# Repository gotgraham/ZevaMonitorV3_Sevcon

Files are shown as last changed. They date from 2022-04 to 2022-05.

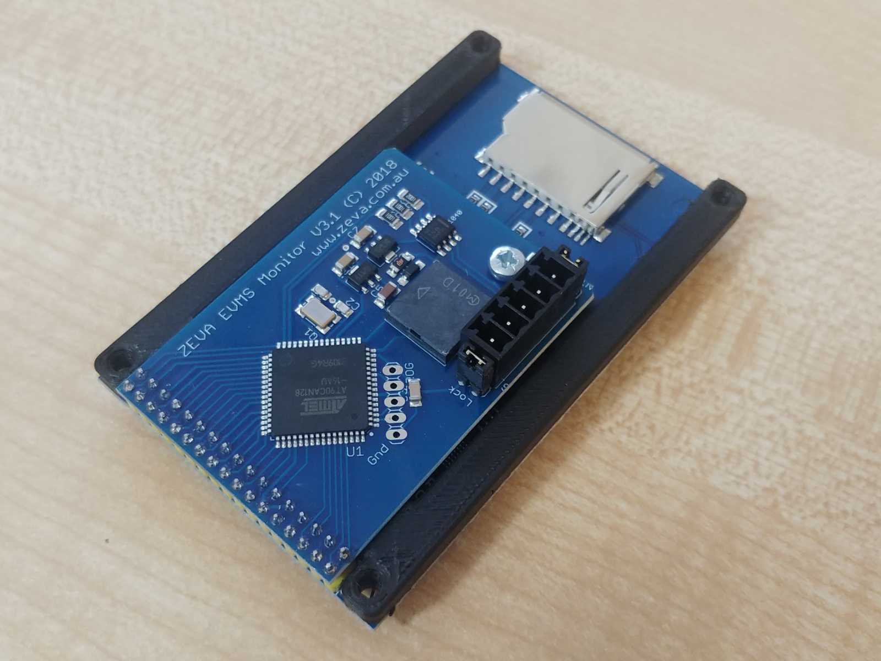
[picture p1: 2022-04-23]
Example Pictures/Assembled internals.jpg

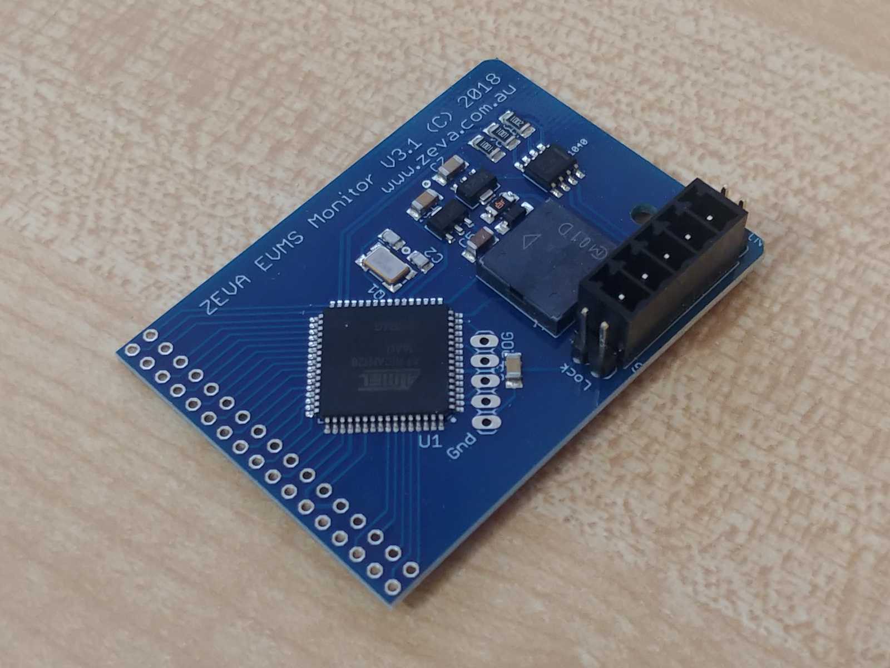
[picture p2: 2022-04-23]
Example Pictures/Control board.jpg

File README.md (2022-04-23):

# ZevaMonitorV3_SevconGen4

This project is based on the now open source Zeva EVMS Monitor V3 from Ian Hooper. It has an MIT license as does Ian's original source.

It retains all the existing EVMS Monitor V3 features, and adds an additional screen for monitoring live parameters from a Sevcon Gen 4 controller.

- Motor Temp
- Motor RPM
- Controller Temp
- Velocity
- Phase Amps
- ...

To build:

Install avr-gcc

From the Firmware directory, run 'make all'. The makefile supports 'make all', 'make clean', and 'make flash'

Status:

 WIP

ZEVA EVMS Monitor V3
  Ian Hooper, August 2021

This archive contains all the files needed to reproduce the ZEVA EVMS Monitor V3, a touchscreen interface device for the EVMS3. Files are provided under the open source MIT license, found at the end of this file. The short version is that you may use these files for any purpose, free of charge, but they don’t come with any warranty or support.

PCB and schematic (.sch) files can be opened in Autodesk Eagle. If you don’t need to modify the design, the Gerber files in the PCB Assembly folder can be sent as-is to a PCB manufacturer to get boards made. Files for PCB assembly are also included, such as a Bill of Materials, centroid files (for pick-and-place machines), and example photos for reference. Parts in the Eagle file may not match the BoM in some cases. If in doubt, trust the BoM.

The LCD panels can be purchased off Alibaba or AliExpress - just search for “3.2 TFT LCD”, and look for pictures that match the example supplied with this download. Some example vendors are TZT, YTF, EQV, HESAI, Roarkit.

The firmware is written is C and can be compiled using AVR-GCC, normally using an IDE such as AVR / Microchip Studio. No claims are made about the quality or readability of the code. (This Monitor code in particular may be a bit of an impenetrable monolith if you’re not familiar with it - my apologies.) A precompiled HEX file is also supplied, which can be loaded onto boards as-is if standard firmware is suitable.

You will need an AVRISP type programming device for transferring firmware to the board, such as AVRISP MK2, STK500 or USBASP. The programming port on the PCB is a row of 5 holes near the microcontroller, with pin order GND, MOSI, MISO, SCK, RESET (with GND end marked). It is different to the usual 3x2 or 5x2 pin port used by AVRISP programmers, so you will need to make an adapter using 5 wires and some 0.1” pin header. Normally the 5x1 pin header can be pressed against the PCB holes during programming (avoids the need to add any connector to the board). The board will need to be powered during programming via 12V supplied to the CAN bus port.

AVR microcontrollers use “fuses” for setting things like the clock speed and brownout detection. The required fuse settings are listed near the top of the C code file.

There is a PCB support bracket that should be 3D printed, which gets fitted between the LCD module and the control board, and fastened to the control board using an M3x6 machine screw. Then the control board can be soldered to the 34x interface pins on the LCD module to complete the internal assembly. There are two housing options supplied, one panel mount which gets attached to the assembly using 4x M3x10 machine screws, or an enclosed housing with foot which gets screwed together using 4x M3x16 countersunk machine screws, and the foot can be attached using an M3x20 machine screw plus M3 nyloc nut. The mating connector for the CAN bus port is Molex 39500-0005. Remember to also fit jumpers to the two 2-pin headers either side of the CAN port, for the CAN termination resistor and to disable settings lock.

Once assembled and programmed, the EVMS Monitor should be ready to use. Please review the EVMS3 user manual for further information about installation and operation.

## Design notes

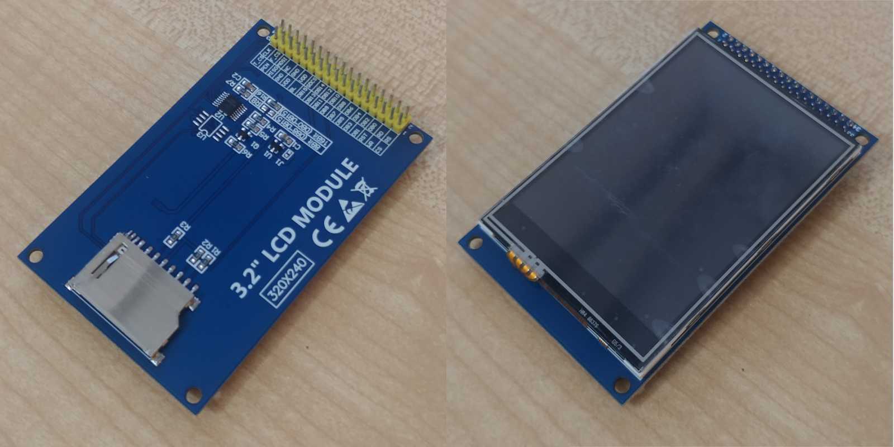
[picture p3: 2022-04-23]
Example Pictures/LCD Module.jpg

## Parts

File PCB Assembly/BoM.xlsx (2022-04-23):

Qty | Designator | Description or part number | Package | Total pads | Total pins
1 | Q1 | ABM3B-16.000MHZ-10-1-U-T | CTS406 | 4
1 | D1 | B5819W-TP | SOD123 | 2
2 | CANTERM, CONFIG_LOCK | Standard 0.1" pitch pin headers, 2x1 | 1X02 |  | 4
0 | PROG | Leave empty | 1X05
0 | QDTECH_LCD | Leave empty | 2X17
1 | C3 | 0.1uF 50V 1206 X7R capacitor | C1206 | 2
1 | R4 | 120ohm 1% 1206 resistor | R1206 | 2
2 | C1, C2 | 10pF 0805 C0G capacitor | C0805 | 4
2 | R1, R2 | 1Kohm 1% 1206 resistor | R1206 | 4
2 | C7, C9 | 1uF 16V 1206 X7R capacitor | C1206 | 4
1 | U$5 | 0ZCJ0020FF2E | 1206 | 2
1 | R3 | 2Kohm 1% 1206 resistor | R1206 | 2
1 | IC1 | L78L33ABUTR | SOT89R | 3
1 | C5 | 47uF 16V 1206 ceramic capacitor | C1206 | 2
1 | IC2 | L78L05ABUTR | SOT89R | 3
1 | U1 | AT90CAN64-16AU | TQFP64-0.8MM | 64
1 | SN65HVD1040 | SN65HVD1040QDRQ1 | SOIC8 | 8
1 | U$1 | 39501-1005 | MOLEX-39501-1005 |  | 5
1 | U$6 | PKLCS1212E4001-R1 | PKLCS1212E_PIEZO | 2
21 |  | (TOTALS LINE) |  | 108 | 9

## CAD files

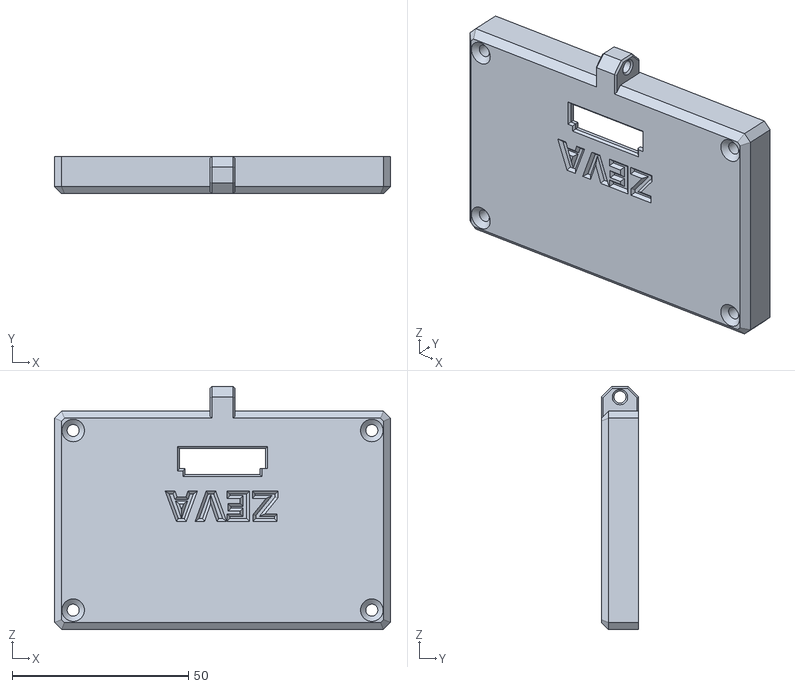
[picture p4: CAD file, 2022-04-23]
Housing/Enclosed Housing - Rear.STL
95.4 x 10.6 x 69.0

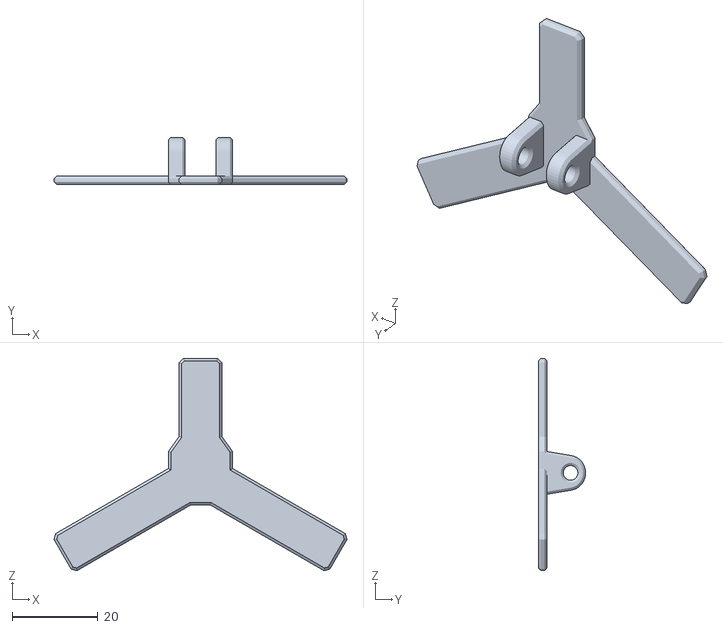
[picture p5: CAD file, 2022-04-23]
Housing/Enclosed Housing - Mounting Foot.STL
68.5 x 11.0 x 49.6

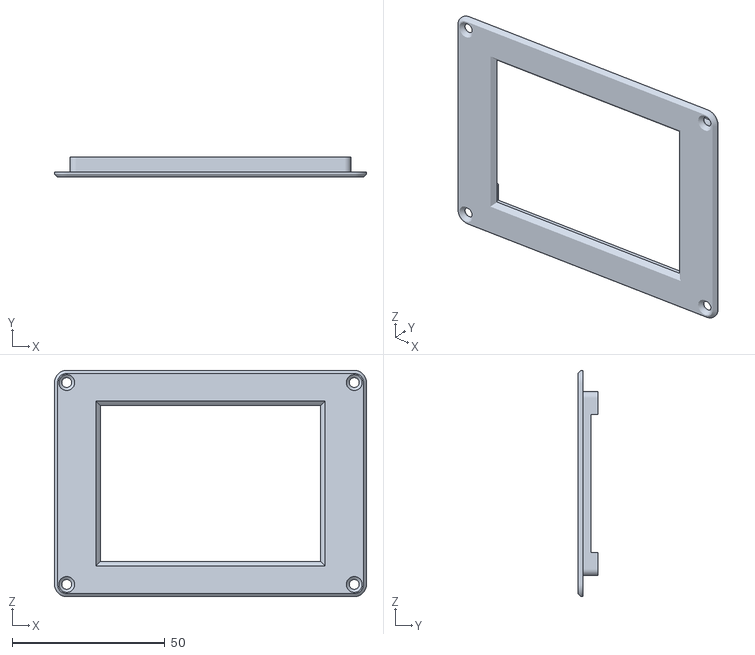
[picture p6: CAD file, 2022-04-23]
Housing/Panel Mount Fascia.STL
102.0 x 6.60 x 74.0

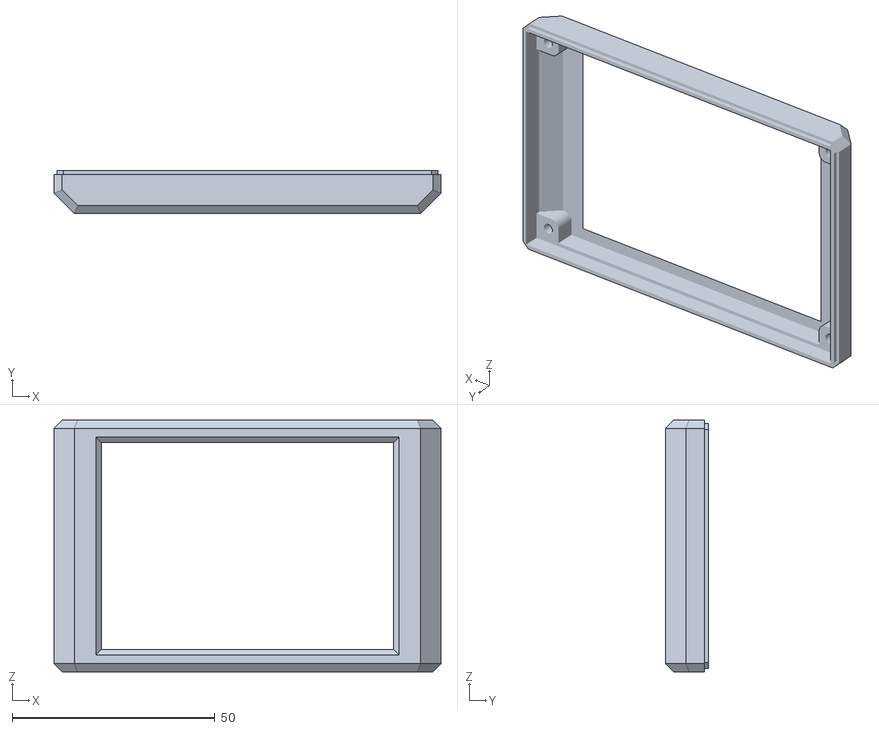
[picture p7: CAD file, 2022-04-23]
Housing/Enclosed Housing - Front.STL
95.4 x 10.6 x 62.0

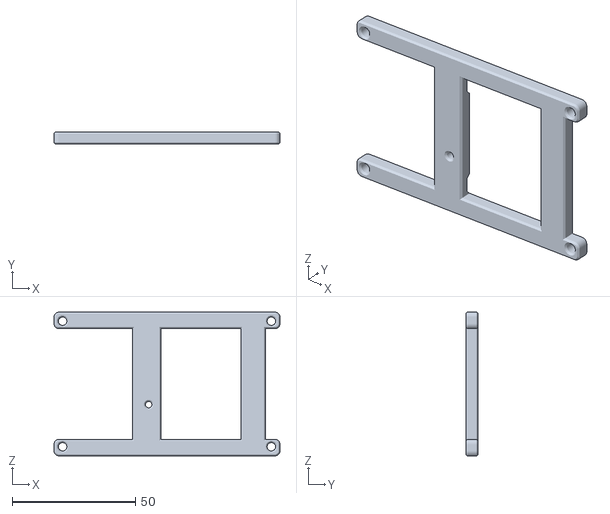
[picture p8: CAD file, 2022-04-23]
Housing/PCB Support.STL
91.8 x 5.00 x 58.4

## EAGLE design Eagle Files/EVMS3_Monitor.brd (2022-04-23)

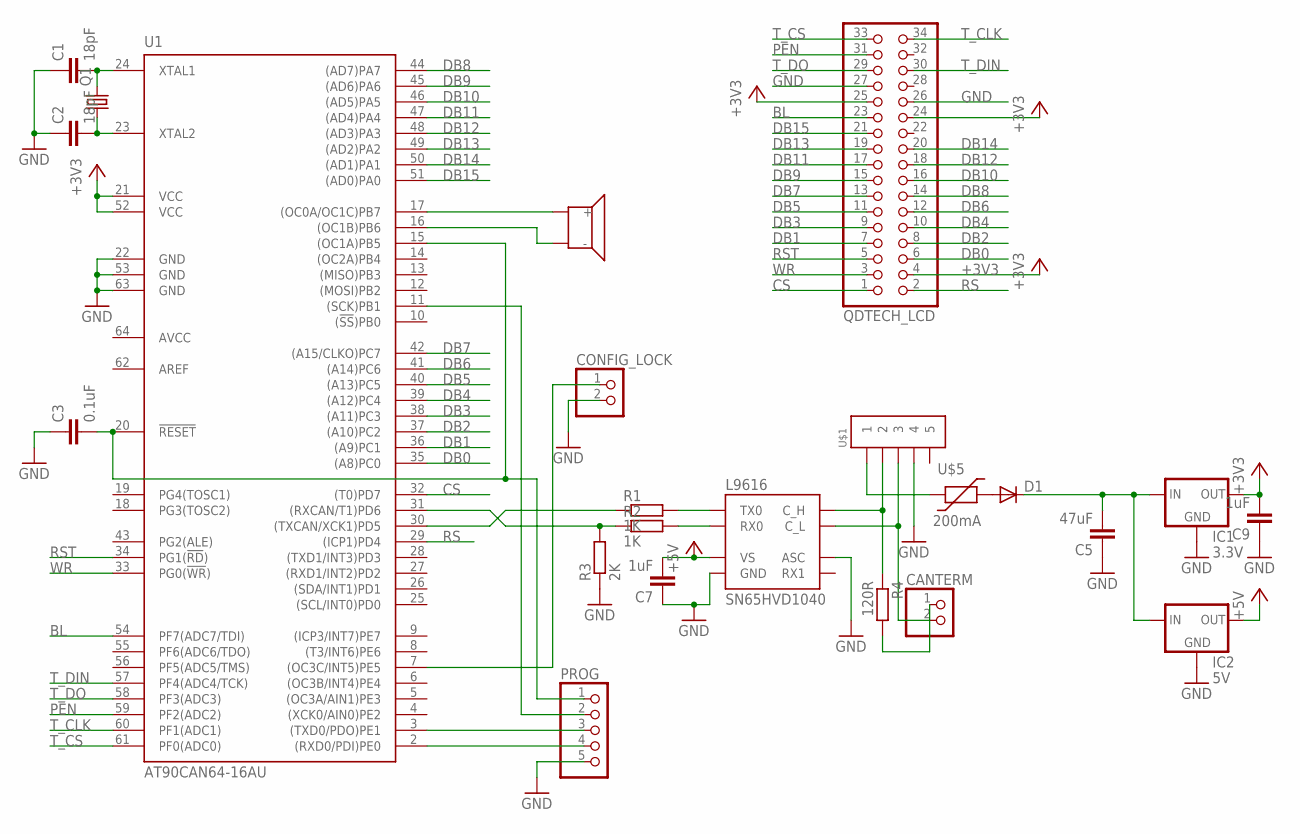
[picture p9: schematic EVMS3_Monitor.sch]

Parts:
C1, C2: 18pF; C0805
C3: 0.1uF; C1206
C5: 47uF; C1206
C7, C9: 1uF; C1206
CANTERM: PINHD-1X2; 1X02
CONFIG_LOCK: PINHD-1X2; 1X02
D1: DIODE-SOD123; SOD123
IC1: 3.3V; SOT89R
IC2: 5V; SOT89R
PROG: PINHD-1X5; 1X05
Q1: CRYSTALCTS406; CTS406
QDTECH_LCD: PINHD-2X17; 2X17
R1, R2: 1K; R1206
R3: 2K; R1206
R4: 120R; R1206
SN65HVD1040: L9616; SOIC8
U1: AT90CAN64-16AU; TQFP64-0.8MM
U$1: MOLEX-39502-1005VERT; MOLEX-39501-1005
U$5: 200mA; 1206
U$6: MURATA_PIEZO; PKLCS1212E_PIEZO

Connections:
+3V3: C9.2, IC1.2 (OUT), QDTECH_LCD.4, QDTECH_LCD.24, QDTECH_LCD.25, U1.21 (VCC), U1.52 (VCC)
+5V: C7.2, IC2.2 (OUT), SN65HVD1040.P$3 (VS)
AVCC: U1.64 (AVCC)
BL: QDTECH_LCD.23, U1.54 (PF7(ADC7/TDI))
BUZZER: U1.17 ((OC0A/OC1C)PB7), U$6.1 (+)
CS: QDTECH_LCD.1, U1.32 ((T0)PD7)
DB0: QDTECH_LCD.6, U1.35 ((A8)PC0)
DB1: QDTECH_LCD.7, U1.36 ((A9)PC1)
DB2: QDTECH_LCD.8, U1.37 ((A10)PC2)
DB3: QDTECH_LCD.9, U1.38 ((A11)PC3)
DB4: QDTECH_LCD.10, U1.39 ((A12)PC4)
DB5: QDTECH_LCD.11, U1.40 ((A13)PC5)
DB6: QDTECH_LCD.12, U1.41 ((A14)PC6)
DB7: QDTECH_LCD.13, U1.42 ((A15/CLKO)PC7)
DB8: QDTECH_LCD.14, U1.44 ((AD7)PA7)
DB9: QDTECH_LCD.15, U1.45 ((AD6)PA6)
DB10: QDTECH_LCD.16, U1.46 ((AD5)PA5)
DB11: QDTECH_LCD.17, U1.47 ((AD4)PA4)
DB12: QDTECH_LCD.18, U1.48 ((AD3)PA3)
DB13: QDTECH_LCD.19, U1.49 ((AD2)PA2)
DB14: QDTECH_LCD.20, U1.50 ((AD1)PA1)
DB15: QDTECH_LCD.21, U1.51 ((AD0)PA0)
GND: C1.1, C2.1, C3.1, C5.1, C7.1, C9.1, CONFIG_LOCK.2, IC1.4 (GND), IC2.4 (GND), PROG.5, QDTECH_LCD.26, QDTECH_LCD.27, R3.1, SN65HVD1040.P$2 (GND), SN65HVD1040.P$8 (ASC), U1.22 (GND), U1.53 (GND), U1.63 (GND), U$1.4
unnamed: C3.2, PROG.1, U1.15 ((OC1A)PB5), U1.20 (!RESET)
unnamed: C1.2, Q1.3 (2), U1.24 (XTAL1)
unnamed: C2.2, Q1.1, U1.23 (XTAL2)
unnamed: PROG.4, U1.2 ((RXD0/PDI)PE0)
unnamed: PROG.3, U1.3 ((TXD0/PDO)PE1)
unnamed: PROG.2, U1.11 ((SCK)PB1)
unnamed: R1.1, U1.30 ((TXCAN/XCK1)PD5)
unnamed: C5.2, D1.C, IC1.1 (IN), IC2.1 (IN)
unnamed: R2.1, R3.2, U1.31 ((RXCAN/T1)PD6)
unnamed: R1.2, SN65HVD1040.P$1 (TX0)
unnamed: R2.2, SN65HVD1040.P$4 (RX0)
unnamed: CONFIG_LOCK.1, U1.7 ((OC3C/INT5)PE5)
unnamed: R4.1, SN65HVD1040.P$7 (C_H), U$1.2
unnamed: CANTERM.2, SN65HVD1040.P$6 (C_L), U$1.3
unnamed: CANTERM.1, R4.2
unnamed: U1.16 ((OC1B)PB6), U$6.2 (-)
unnamed: D1.A, U$5.P$2
unnamed: U$1.1, U$5.P$1
PEN: QDTECH_LCD.31, U1.59 (PF2(ADC2))
RS: QDTECH_LCD.2, U1.29 ((ICP1)PD4)
RST: QDTECH_LCD.5, U1.34 (PG1(!RD!))
T_CLK: QDTECH_LCD.34, U1.60 (PF1(ADC1))
T_CS: QDTECH_LCD.33, U1.61 (PF0(ADC0))
T_DIN: QDTECH_LCD.30, U1.57 (PF4(ADC4/TCK))
T_DO: QDTECH_LCD.29, U1.58 (PF3(ADC3))
WR: QDTECH_LCD.3, U1.33 (PG0(!WR!))

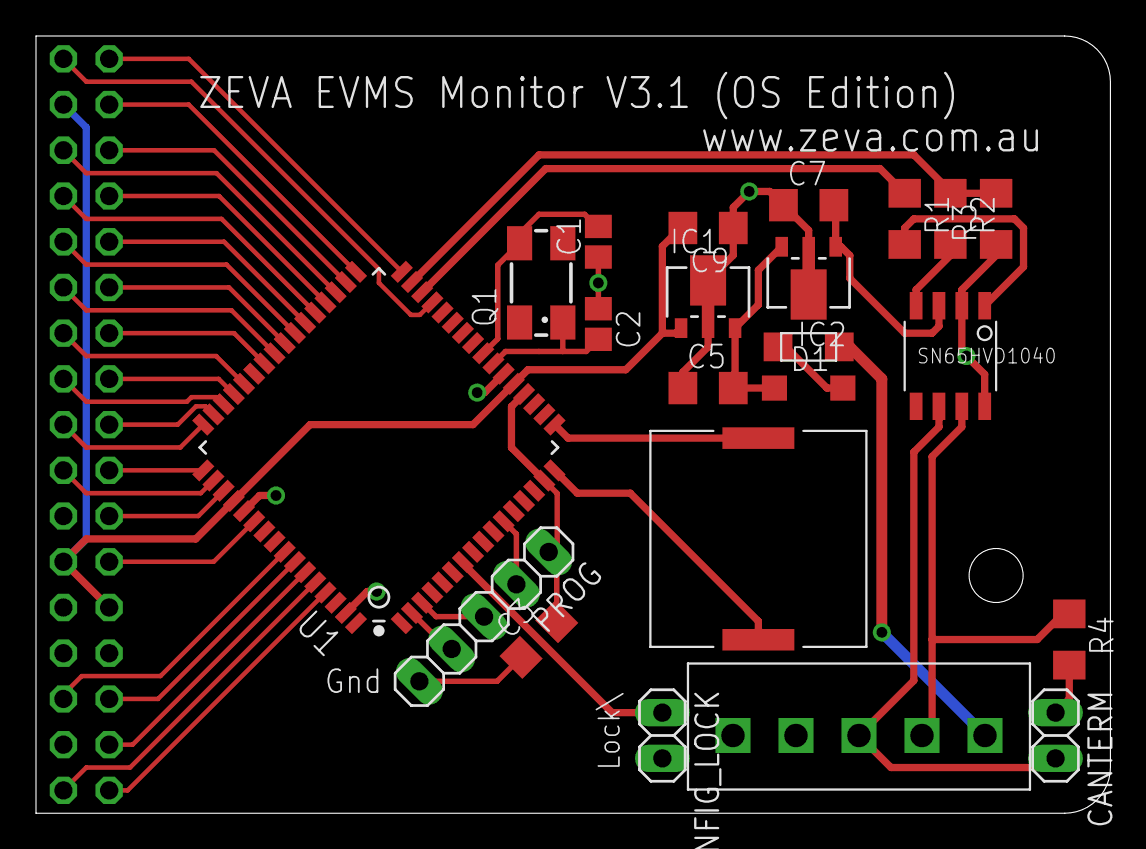
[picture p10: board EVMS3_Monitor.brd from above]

Board: 2 copper layers, 59.7 x 43.2 mm, 23 parts (1 on the bottom side), 48 nets.

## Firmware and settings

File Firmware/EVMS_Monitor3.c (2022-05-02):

// EVMS Monitor V3
// Open Source version, released under MIT License (see Readme file)
// Last modified by Ian Hooper (ZEVA), August 2021

// Code for AT90CAN64 (also suitable for AT90CAN128)
// Fuses: 16Mhz external crystal, CKDIV8 off, JTAGEN off

// Note: Various #defined build options found in Common.h file

#define __DELAY_BACKWARD_COMPATIBLE__

#define DISPLAY_TYPE	ILI9341		// SSD1289 or ILI9325 or ILI9341
#define SHOW_TOUCH_LOCATION	0 // Used for debugging touchscreen - writes touched coords in top left
#define FAKE_EVMS	0 // Use to test things if no EVMS is present
#define MONITOR // Modifies some stuff in the Common.h header

#define MAX_BMS_MODULES	16

#include <inttypes.h>
#include <stdlib.h>
#include <string.h>
#include <avr/io.h>
#include <avr/eeprom.h>
#include <avr/interrupt.h>
#include <avr/pgmspace.h>
#include <util/delay.h>
#include <stdbool.h>

#include "Common.h"
#include "Touchscreen.h"
#include "config.h"
#include "can_lib.h"

// Colour theme - only partially implemented
#define BGND_COLOUR		BLACK
#define LABEL_COLOUR	BLUE // RED
#define TEXT_COLOUR		WHITE // RED
#define CHARGING_COLOUR	BLUE // RED
#define RUNNING_COLOUR	GREEN // RED
#define SOC_COLOUR		0		// or 0 to use green-to-red dynamic colouring

#define BUZZER	(1<<PB7)
#define BUZZER2	(1<<PB6)

#define CONFIG_LOCK	(PIND & (1<<PD0)) // Config lock normally pulled down (off) by jumper, i.e remove jumper to lock
#define CONFIG_LOCK2 (PINE & (1<<PE5)) // PCB version 3.1 reassigned this - but code should support both

#ifdef NEW_LCD
#define BACKLIGHT		(1<<PF7)
#define BACKLIGHT_PORT	PORTF
#define BACKLIGHT_DDR	DDRF
#else
#define BACKLIGHT		(1<<PD7)
#define BACKLIGHT_PORT	PORTD
#define BACKLIGHT_DDR	DDRD
#endif

// Initialising all the buttons
typedef struct
{
	int x, y, width;
	U16 colour;
	char* text;
	bool isTouched;
} Button;

Button enterSetupButton = { 160, 30, 220, BLUE, "Enter Setup", false };
Button resetSocButton = { 160, 70, 220, GREEN, "Reset SoC", false };
Button zeroCurrentButton = { 160, 110, 220, GREEN, "Zero Current", false };
Button displayOffButton = { 160, 150, 220, GREEN, "Display Off", false };
Button exitOptionsButton = { 160, 190, 220, ORANGE, "Exit Options", false };

Button nextBmsModuleButton = { 260, 200, 100, GREEN, "Next", false };
Button prevBmsModuleButton = { 60, 200, 100, GREEN, "Prev", false };

Button changeSetupPageButtonLeft = { 40, 25, 80, BLUE, "<", false };
Button changeSetupPageButtonRight = { 280, 25, 80, BLUE, ">", false };
Button changeParameterButtonLeft = { 40, 90, 80, BLUE, "<", false };
Button changeParameterButtonRight = { 280, 90, 80, BLUE, ">", false };
Button changeValueButtonLeft = { 40, 155, 80, BLUE, "<", false };
Button changeValueButtonRight = { 280, 155, 80, BLUE, ">", false };
Button exitSetupButton = { 160, 207, 160, ORANGE, "Exit Setup", false };

Button* touchedButton = 0;

short cellVoltages[MAX_BMS_MODULES][12]; // Buffer for holding last cell voltages
U8 bmsTemps[MAX_BMS_MODULES][2];

long current = 0;
int currentSensorTimeout = 0;
char haveReceivedCurrentData = false;

unsigned char mcStatusBytes[8];
unsigned char sevStatus0Bytes[8];
unsigned char sevStatus1Bytes[8];

short mcCanTimeout = 0;

char haveReceivedEVMSData = 0;
char haveReceivedMCData = 1;

short chargerCommsTimeout[3] = { 0, 0, 0 };

short ticksSincePowerOn = 0;

// Display pages
enum { EVMS_CORE, MOTOR_CONTROLLER, TC_CHARGER, BMS_SUMMARY, BMS12_DETAILS, NUM_KNOWN_DEVICES };

// Function declarations
void PrepareCanRX(unsigned char mob);
void ProcessCanRX(unsigned char mob);
void HandleTouchDown();
void HandleTouchUp();
void DoSetupButtons(char isKeyRepeat);
void TransmitSettings();
void TransmitGaugeState();
static inline void Beep(short ticks);
static inline void UpdateBuzzer();
void AddDecimalPoint(char* buffer);
void AddDecimalPoint2(char* buffer);
void SetupPorts();
char LoadSettingsFromEEPROM();
void SaveSettingsToEEPROM();
void CanTX(long packetID, unsigned char* data, unsigned char length, unsigned char delayAfterSending);
void RenderStartupScreen();
void RenderMainView();
void RenderMainViewNoCurrentSensor();
void RenderLiteIdleScreen();
void RenderMCStatus();
void RenderChargerStatus();
void RenderThreeChargerStatus();
void RenderBMSSummary();
void RenderBMSDetails();
void RenderWarningOverlay();
void RenderOptionsButtons();
static inline void RenderBorderBox(int lx, int ly, int rx, int ry, U16 Fcolor, U16 Bcolor);
void RenderButton(Button* button, bool needsRedraw);
void RenderSettings();

// Global variables

#define NUM_RX_MOBS	4 // Four RX MOBs for CAN messages
st_cmd_t rxMsg[NUM_RX_MOBS];
U8 rxData[NUM_RX_MOBS][8];

U8 txData[8]; // CAN transmit buffer

char buffer[30]; // Used for sprintf functions

short ticks = 0; // For main loop timing

volatile uint8_t evmsStatusBytes[8];

signed char displayedPage = MOTOR_CONTROLLER;

volatile bool displayNeedsFullRedraw = true;
bool showOptionsButtons;
bool showStartupScreen = true;

short coreStatus;
char isBMS16 = false; // Monitor can tell the difference based on CAN data, changes displays etc a little
char isActuallyBMS12i = false; // has a bit of a dirty hack to differentiate BMS16 and BMS12i

unsigned char error = NO_ERROR;
char evmsCommsTimer = 0;
char resetSoCsent = false;

short beepTimer = 0;
short errorBeeperTimeout = 0;
short touchTimer;
int touchX, touchY;
int touchBufferX[10], touchBufferY[10];

enum { NOTHING_TO_SEND, SEND_RESET_SOC, SEND_ZERO_CURRENT, SEND_ENTER_SETUP, SEND_GAUGE_STATE, SEND_SETTINGS, SEND_ACK_ERROR };
short canToGo;

short displayBrightness = 255;
short targetDisplayBrightness; // (Used for smoothly fading brightness)
bool  displayDimmed;
bool  headlightsOn = 0;

char canTXing = false;

bool setupMode = false;

int numCells = 0;

enum { GENERAL_SETTINGS, MC_SETTINGS, PACK_SETUP };
char settingsPage = GENERAL_SETTINGS;
short currentParameter = 0;
short currentBmsModule = 0;

short mcCurrentParameter = 0;

typedef struct {
	// These come from the charger
	short instVoltage;
	short instCurrent;
	unsigned char statusBits;
	unsigned char temp;
	// These go to the charger
	short targetVoltage;
	short targetCurrent;
	char controlBit;
} ChargerData;
ChargerData charger[3] = {{ 0, 0, 0, 0, 0, 0, 0 }, { 0, 0, 0, 0, 0, 0, 0 }, { 0, 0, 0, 0, 0, 0, 0 }};
char haveReceivedChargerData = false;
char numChargers = 1; // Gets set to 3 if we receive data from third charger

static inline bool ButtonTouched(Button* button)
{
	return (touchX >= button->x-button->width/2 && touchX <= button->x+button->width/2
		&& touchY >= button->y && touchY <= button->y + 32);
}

static inline void DisplayOn(bool on, bool shouldSaveToEEPROM)
{
	if (true) //on)
	{
		if (displayDimmed || headlightsOn)
			targetDisplayBrightness = 254 - settings[NIGHT_BRIGHTNESS]*settings[NIGHT_BRIGHTNESS] * 5/2;
			// May 2016: Testing quadratic display brightness
			// April 2019: Using 254 so there's a difference between 0% night brightness and actually off (255), though both are black
		else
			targetDisplayBrightness = 0; // Full bright
	}
	else
		targetDisplayBrightness = 255;

	if (shouldSaveToEEPROM)
	{
		eeprom_write_byte((U8*)EEPROM_DISPLAY_BRIGHTNESS, targetDisplayBrightness);
		eeprom_write_byte(0, 0); // Park EEPROM pointer to prevent corruption
	}
}

char toggley;
SIGNAL(TIMER0_OVF_vect) // Called at 7812Hz, i.e every 2048 cycles of 16Mhz clock
{
	ticks++; // Used for main loop timing

#ifdef NEW_LCD
	BACKLIGHT_PORT &= ~BACKLIGHT;

	if (beepTimer > 0)
	{
		if (toggley)
		{
			PORTB |= BUZZER;
			PORTB &= ~BUZZER2;
			toggley = 0;
		}
		else
		{
			PORTB &= ~BUZZER;
			PORTB |= BUZZER2;
			toggley = 1;
		}
	}
	else
		PORTB &= ~(BUZZER + BUZZER2); // Turn both off if not beeping
#else
	BACKLIGHT_PORT |= BACKLIGHT;
#endif

	if (!canTXing && (ticks & 0x07) == 0) // every 8th interrupt, or around 1000hz
	{
		for (int mob=0; mob<NUM_RX_MOBS; mob++)
		{
			U8 temp = can_get_status(&rxMsg[mob]);

			if (temp == CAN_STATUS_COMPLETED) // Then we have received a frame
				ProcessCanRX(mob);

			if (temp == CAN_STATUS_ERROR)
				PrepareCanRX(mob); // And flad a comms error?
		}
	}
}

SIGNAL(TIMER0_COMP_vect)
{
	if (displayBrightness < 254) // 254 is for 0% night brightness, and 255 is for actually off, but both should have no backlight
#ifdef NEW_LCD
		BACKLIGHT_PORT |= BACKLIGHT;
#else
		BACKLIGHT_PORT &= ~BACKLIGHT;
#endif
}

SIGNAL(TIMER1_OVF_vect) // Interrupts at about 30Hz
{
	// Update display brightness
	if (targetDisplayBrightness > displayBrightness)
		displayBrightness += Cap(targetDisplayBrightness-displayBrightness, 0, 15); // Change by 15 maximum
	if (targetDisplayBrightness < displayBrightness)
		displayBrightness -= Cap (displayBrightness-targetDisplayBrightness, 0, 15);

	// Stay dark for half second to receive data from available devices - suppress initial "Waiting for data" page
	if (ticksSincePowerOn < 1) displayBrightness = 255;

	OCR0A = displayBrightness; // Updates backlight PWM, inverted due to PNP transistor

	// Poll touchscreen
	if (Touch_DataAvailable())
	{
		Touch_Read();

		touchTimer++;
		//touchX = Touch_GetX(); // these now in function below - delete here
		//touchY = Touch_GetY();
		HandleTouchDown();
	}
	else
	{
		if (touchTimer > 0) HandleTouchUp();

		touchTimer = 0;
		touchX = -1;
		touchY = -1;
	}

	UpdateBuzzer();
}

void PrepareCanRX(unsigned char mob)
{
	rxMsg[mob].pt_data = rxData[mob];
	for (int n=0; n<8; n++) rxData[mob][n] = 0;

	if (USE_29BIT_IDS) rxMsg[mob].ctrl.ide = true;

	rxMsg[mob].cmd = CMD_RX_DATA;

	while (can_cmd(&rxMsg[mob]) != CAN_CMD_ACCEPTED) { } // Wait for RX command to be completed
}

// This function gets called when a new CAN message is received
void ProcessCanRX(unsigned char mob)
{
	long packetID = rxMsg[mob].id.std;
	if (USE_29BIT_IDS) packetID = rxMsg[mob].id.ext;

	if (packetID >= BMS_BASE_ID && packetID < BMS_BASE_ID+MAX_BMS_MODULES*10+10) // Packet ID within BMS module range
	{
		int moduleID = (packetID - BMS_BASE_ID)/10;
		int packetType = packetID - BMS_BASE_ID - moduleID*10;

		if (moduleID < MAX_BMS_MODULES)
		{
			switch (packetType)
			{
				case BMS_REPLY1:
					for (int n=0; n<4; n++)
						cellVoltages[moduleID][n] = (rxData[mob][n*2]<<8) + rxData[mob][n*2+1];
					break;

				case BMS_REPLY2:
					for (int n=0; n<4; n++)
						cellVoltages[moduleID][n+4] = (rxData[mob][n*2]<<8) + rxData[mob][n*2+1];
					break;

				case BMS_REPLY3:
					for (int n=0; n<4; n++)
						cellVoltages[moduleID][n+8] = (rxData[mob][n*2]<<8) + rxData[mob][n*2+1];
					if (moduleID == 0 && isBMS16) isActuallyBMS12i = true; // If received this third voltages set, sender must be BMS12i
					break;

				case BMS_REPLY4:
					bmsTemps[moduleID][0] = rxData[mob][0];
					bmsTemps[moduleID][1] = rxData[mob][1];
					break;
			}
		}
	}
	else switch (packetID)
	{
		case CORE_BROADCAST_STATUS:
			for (int n=0; n<8; n++) evmsStatusBytes[n] = rxData[mob][n];
			evmsCommsTimer = 0;
			haveReceivedEVMSData = true;
			if (evmsStatusBytes[5] == 255)
			{
				isBMS16 = true;
				displayOffButton.text = "Power off";
				//displayOffButton.colour = BLUE;
			}
			headlightsOn = evmsStatusBytes[6]>>7;
			DisplayOn(targetDisplayBrightness != 255, false);
			break;

		case CAN_CURRENT_SENSOR_ID:
			current = ((long)rxData[mob][0]<<16) + ((long)rxData[mob][1]<<8) + (long)rxData[mob][2] - 8388608L;
			currentSensorTimeout = 4; // 1 second timeout
			if (!haveReceivedCurrentData)
			{
				haveReceivedCurrentData = true;
				displayNeedsFullRedraw = true;
			}
			break;

		case MC_STATUS_PACKET_ID:
			for (int n=0; n<8; n++) mcStatusBytes[n] = rxData[mob][n];
			mcCanTimeout = 4;
			haveReceivedMCData = true;
			/*
			if (showStartupScreen && ticksSincePowerOn >= 2) // MC has lower priority than EVMS, let EVMS go first
			{
				showStartupScreen = false;
				displayNeedsFullRedraw = true;
				displayedPage = MOTOR_CONTROLLER;
			}
			*/
			break;

		case SEV_STATUS_0:
			// <MotorTemp 16t> <Throttle Input Voltage 16> <RPM 32>
			for (int n=0; n<8; n++) sevStatus0Bytes[n] = rxData[mob][n];
			mcCanTimeout = 4;
			haveReceivedMCData = true;
			break;

		case SEV_STATUS_1:
			// <Dig Inputs 8> <Cap Voltage 16> <Batt Current 16> <Heatsink Temp 8> <Batt voltage 16>
			for (int n=0; n<8; n++) sevStatus1Bytes[n] = rxData[mob][n];
			mcCanTimeout = 4;
			haveReceivedMCData = true;
			break;

		case MC_SEND_SETTINGS_ID:
			for (int n=0; n<4; n++) mcSettings[n] = rxData[mob][n]; // First four match 1:1
			mcSettings[MC_RAMP_RATE] = rxData[mob][4]&0b00001111; // Bottom 4 bits hold ramp rate
			mcSettings[MC_SPEED_CONTROL_TYPE] = (rxData[mob][4]&0b00110000)>>4;
			mcSettings[MC_TORQUE_CONTROL_TYPE] = (rxData[mob][4]&0b11000000)>>6;
			for (int n=5; n<8; n++) mcSettings[n+2] = rxData[mob][n];
			break;

		case TC_CHARGER1_RX_ID:
			charger[0].targetVoltage = rxData[mob][0]*256+rxData[mob][1];
			charger[0].targetCurrent = rxData[mob][2]*256+rxData[mob][3];
			charger[0].controlBit = rxData[mob][4];
			break;

		case TC_CHARGER1_TX_ID:
			charger[0].instVoltage = rxData[mob][0]*256+rxData[mob][1];
			charger[0].instCurrent = rxData[mob][2]*256+rxData[mob][3];
			charger[0].statusBits = rxData[mob][4];
			charger[0].temp = rxData[mob][5];
			chargerCommsTimeout[0] = 12; // Three seconds with 4hz loop
			haveReceivedChargerData = true;
			break;

		case TC_CHARGER2_RX_ID:
			charger[1].targetVoltage = rxData[mob][0]*256+rxData[mob][1];
			charger[1].targetCurrent = rxData[mob][2]*256+rxData[mob][3];
			charger[1].controlBit = rxData[mob][4];
			break;

		case TC_CHARGER2_TX_ID:
			charger[1].instVoltage = rxData[mob][0]*256+rxData[mob][1];
			charger[1].instCurrent = rxData[mob][2]*256+rxData[mob][3];
			charger[1].statusBits = rxData[mob][4];
			charger[1].temp = rxData[mob][5];
			chargerCommsTimeout[1] = 12; // Three seconds with 4hz loop
			if (numChargers<2) numChargers = 2;
			break;

		case TC_CHARGER3_RX_ID:
			charger[2].targetVoltage = rxData[mob][0]*256+rxData[mob][1];
			charger[2].targetCurrent = rxData[mob][2]*256+rxData[mob][3];
			charger[2].controlBit = rxData[mob][4];
			break;

		case TC_CHARGER3_TX_ID:
			charger[2].instVoltage = rxData[mob][0]*256+rxData[mob][1];
			charger[2].instCurrent = rxData[mob][2]*256+rxData[mob][3];
			charger[2].statusBits = rxData[mob][4];
			charger[2].temp = rxData[mob][5];
			chargerCommsTimeout[2] = 12; // Three seconds with 4hz loop
			numChargers = 3;
			break;
	}

	PrepareCanRX(mob);
}

void SetError(U8 newError)
{
	if (error != newError)
	{
		displayNeedsFullRedraw = true;
		showOptionsButtons = false;
		DisplayOn(true, false);
		errorBeeperTimeout = 120; // Beep 120 times = 60 seconds max with new error
	}
	error = newError;
}

void CalculateNumCells()
{
	numCells = 0;
	for (int id=0; id<MAX_BMS_MODULES; id++) numCells += bmsCellCounts[id];
}

void TestBeep(int delay, int osc)
{
	for (int n=0; n<osc; n++)
	{
		PORTB |= BUZZER;
		PORTB &= ~BUZZER2;
		_delay_us(delay);
		PORTB &= ~BUZZER;
		PORTB |= BUZZER2;
		_delay_us(delay);
	}
}

int main()
{
	SetupPorts();

	OCR0A = 255;

	_delay_ms(100); // Wait for LCD to power up
	TFT_Init(DISPLAY_TYPE, DISPLAY_TYPE == ILI9325);

	Touch_Init();

	can_init(0);

	char result = LoadSettingsFromEEPROM();
	if (result == EEPROM_BLANK || result == EEPROM_CORRUPT)
	{
		SetError(CORRUPT_EEPROM_ERROR);
		SaveSettingsToEEPROM();
	}

	CalculateNumCells();

	int lastDisplayBrightness = eeprom_read_byte((U8*)EEPROM_DISPLAY_BRIGHTNESS);
	eeprom_write_byte(0, 0); // Park EEPROM pointer to prevent corruption
	if (lastDisplayBrightness == 0) displayDimmed = false; else displayDimmed = true;
	DisplayOn(lastDisplayBrightness != 255, false); // Sends true unless old display brightness was off

	for (int mob=0; mob<NUM_RX_MOBS; mob++) PrepareCanRX(mob);

#ifdef NEW_LCD
	if (settings[BUZZER_ON]) // Do a bit of a startup chirp
	{
		TestBeep(160, 50);
		TestBeep(40, 200);
	}
#endif

	sei(); // Enable interrupts

	while (1)
	{
		// Timed polling for things like comms timeouts
		while (ticks > 1952) // 4Hz
		{
			ticks -= 1952;

			if (ticksSincePowerOn < 100) ticksSincePowerOn++;

			// Check for comms timeouts
			if (evmsCommsTimer < 100) evmsCommsTimer++;
			if (evmsCommsTimer == 4)
			{
				if (mcStatusBytes[0] == 0)
					SetError(CORE_COMMS_ERROR); // No core OR motor controller detected - set error
				else
					displayNeedsFullRedraw = true; // We detected a motor controller, so redraw to view that
			}

			if (error == CORE_COMMS_ERROR && evmsCommsTimer < 4) SetError(NO_ERROR); // Self-reset if received data

			if (currentSensorTimeout > 0)
				currentSensorTimeout--;
			else
				current = 0;

			if (mcCanTimeout > 0) mcCanTimeout--; // Only used in the MC status page

			for (int n=0; n<3; n++)
			{
				if (chargerCommsTimeout[n] > 0)
					chargerCommsTimeout[n]--;
				else
				{	// No data for a while - set values to zero
					charger[n].instVoltage = 0;
					charger[n].instCurrent = 0;
					charger[n].statusBits = 0;
				}
			}

			if (FAKE_EVMS) // Then pretend we have received EVMS status message, and transmit BMS ID 0 request
			{
				int ampHours = 10000;
				int voltage = 1234;
				evmsStatusBytes[0] = 0b00000000;	// Status in bottom 3 bits, error top 5
				evmsStatusBytes[1] = ampHours>>8;
				evmsStatusBytes[2] = ampHours&0xFF;
				evmsStatusBytes[3] = voltage>>8;
				evmsStatusBytes[4] = voltage&0xFF;
				evmsStatusBytes[5] = 123; // Aux voltage
				evmsStatusBytes[6] = 100;// Isolation
				evmsStatusBytes[7] = 23+40; // Temperature
				evmsCommsTimer = 0;
				haveReceivedEVMSData = true;

				txData[0] = txData[1] = 0; // Zero shunt voltage (i.e shunts off)
				CanTX(BMS_BASE_ID + BMS_REQUEST_DATA, txData, 2, 0);
			}
		}

		if (canToGo)
		{
			switch (canToGo)
			{
				case SEND_RESET_SOC:	CanTX(CORE_RESET_SOC, txData, 0, 5); break;
				case SEND_ZERO_CURRENT: CanTX(CAN_ZERO_CURRENT, txData, 0, 5); break;
				case SEND_ENTER_SETUP:
					txData[0] = CORE_SETUP_STATE;
					CanTX(CORE_SET_STATE, txData, 1, 5);
					txData[0] = 0;
					CanTX(MC_RECEIVE_SETTINGS_ID, txData, 1, 0);
					break;
				case SEND_SETTINGS:		TransmitSettings(); break;
				case SEND_GAUGE_STATE:	TransmitGaugeState(); break;
				case SEND_ACK_ERROR: CanTX(CORE_ACKNOWLEDGE_ERROR, &error, 1, 5); break;
				case POWER_OFF: CanTX(POWER_OFF, txData, 0, 5); break;
			}
			canToGo = NOTHING_TO_SEND;
		}

		// LCD update stuff - happens whenever there's free time
		char oldCoreStatus = coreStatus;
		coreStatus = evmsStatusBytes[0]&0x07; // Bottom 3 bits are status
		if (oldCoreStatus != coreStatus) displayNeedsFullRedraw = true;

		char newError = evmsStatusBytes[0]>>3; // Top 5 bytes hold error codes
		if (error < CORE_COMMS_ERROR) SetError(newError); // Only update error with Core error status if a Monitor error isn't pending

		if (showStartupScreen)
		{
			if (haveReceivedEVMSData)
			{
				displayNeedsFullRedraw = true;
				showStartupScreen = false;
			}
			else if (haveReceivedMCData && ticksSincePowerOn > 2)
			{
				displayNeedsFullRedraw = true;
				displayedPage = MOTOR_CONTROLLER;
				showStartupScreen = false;
			}
		}

		if (isBMS16)
		{
			if (displayedPage == EVMS_CORE && settings[SHUNT_SIZE] == 0 /* no shunt */ && !haveReceivedCurrentData)
			{
				displayedPage = BMS_SUMMARY;
				if (!setupMode) displayNeedsFullRedraw = true;
			}
		}

		// Write to display
		if (setupMode)
			RenderSettings();
		else if (error != NO_ERROR && (!settings[STATIONARY_VERSION] || (error != BMS_LOW_WARNING && error != BMS_HIGH_WARNING)))
			RenderWarningOverlay();
		else if (showStartupScreen)
			RenderStartupScreen();
		else if (showOptionsButtons)
			RenderOptionsButtons();
		else if (displayedPage == MOTOR_CONTROLLER)
			RenderMCStatus();
		else if (displayedPage == TC_CHARGER)
			RenderChargerStatus();
		else if (displayedPage == EVMS_CORE)
		{
			if (haveReceivedCurrentData || isBMS16)
				RenderMainView();
			else
				RenderMainViewNoCurrentSensor();
		}
		else if (displayedPage == BMS12_DETAILS)
			RenderBMSDetails();
		else if (displayedPage == BMS_SUMMARY)
			RenderBMSSummary();

		if (SHOW_TOUCH_LOCATION)
		{
			char temp[5];
			itoa(touchX, buffer, 10);
			strcat(buffer, ",");
			itoa(touchY, temp, 10);
			strcat(buffer, temp);
			strcat(buffer, " ");

			TFT_Text(buffer, 0, 0, 1, GREEN, BLACK);
		}
	}
	return 0; // Compiler wants to see it
}

static inline void CheckTouchedButton(Button* button)
{
	if (ButtonTouched(button)) touchedButton = button;
}
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

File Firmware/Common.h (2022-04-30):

// Common header file for EVMS3, BMS12i, BMS16, Monitor
// Has defines, enums, variables and utility functions common to EVMS and Monitor.
// Ideally just keep one copy of this file somewhere and link to it from each separate project

// Open Source version, released under MIT License (see Readme file)
// Last modified by Ian Hooper (ZEVA), August 2021

#define CAN_BAUD        250
#define USE_29BIT_IDS	1 // Or 11-bit IDs if set to 0

#define CAN_BASE_ID		30

#define PACK_CAPACITY_MULTIPLIER	5 // Ah steps in settings, also affects max capacity, normally 5
#define PACK_VOLTAGE_MULTIPLIER		1 // 1 for normal range of 0-400V systems, 2 for double range up to 800V or so
#define BALANCE_TOLERANCE	10 // i.e shunt if this many millivolts above average

#define EEPROM_OFFSET	4
enum { EEPROM_BLANK, EEPROM_CORRUPT, EEPROM_CORRECT };
#define EEPROM_DISPLAY_BRIGHTNESS	120

// CAN PACKET IDs
enum { CORE_BROADCAST_STATUS = CAN_BASE_ID,
	CORE_SET_STATE,
	CORE_RECEIVE_CONFIG1,
	CORE_RECEIVE_CONFIG2,
	CORE_RECEIVE_CONFIG3,
	CORE_RECEIVE_CONFIG4,
	CORE_RECEIVE_CELL_NUMS,
	CORE_ACKNOWLEDGE_ERROR,
	CORE_RESET_SOC,
    POWER_OFF };

#define CAN_CURRENT_SENSOR_ID	40
#define CAN_ZERO_CURRENT		41
#define CAN_EVSE_INTERFACE		45

enum { CORE_REQUEST_CONFIG = 51,
	CORE_SEND_CONFIG1,
	CORE_SEND_CONFIG2,
	CORE_SEND_CONFIG3,
	CORE_SEND_CONFIG4,
	CORE_SEND_CELL_NUMS };

#define BMS_BASE_ID	300
enum { BMS_REQUEST_DATA, BMS_REPLY1, BMS_REPLY2, BMS_REPLY3, BMS_REPLY4 };

// Charger stuff
#define TC_CHARGER1_RX_ID	0x1806E5F4
#define TC_CHARGER1_TX_ID	0x18FF50E5
#define TC_CHARGER2_RX_ID	0x1806E7F4
#define TC_CHARGER2_TX_ID	0x18FF50E7
#define TC_CHARGER3_RX_ID	0x1806E8F4
#define TC_CHARGER3_TX_ID	0x18FF50E8

// Sevcon Gen4
#define SEV_STATUS_0 0x281  // <MotorTemp 16t> <Throttle Input Voltage 16> <RPM 32>
#define SEV_STATUS_1 0x381  // <Dig Inputs 8> <Cap Voltage 16> <Batt Current 16> <Heatsink Temp 8> <Batt voltage 16>

// Motor Controller stuff
enum { NO_MC, MC600C, MC1000C };
enum { MC_STATUS_PACKET_ID = 50, MC_SET_THROTTLE_ID, MC_RECEIVE_SETTINGS_ID, MC_SEND_SETTINGS_ID };

enum { // MC status / errors
	MC_NO_ERROR,
	MC_SLEEPING,
	MC_DESAT_ERROR,
	MC_CURRENT_SENSOR_FAULT,
	MC_TEMP_SENSOR_FAULT,
	MC_UNDER_VOLTAGE,
	MC_OVER_VOLTAGE,
	MC_LOW_LOGIC_VOLTAGE,
	MC_THROTTLE_ERROR,
	MC_THERMAL_CUTBACK_ERROR,
	MC_THERMAL_SHUTDOWN_ERROR,
	MC_NUM_ERRORS };

enum { // MC settings
	MC_MIN_BATT_VOLTAGE,
	MC_MAX_MOTOR_VOLTAGE,
	MC_MAX_MOTOR_CURRENT,
	MC_MAX_BATT_CURRENT,
	MC_RAMP_RATE,
	MC_SPEED_CONTROL_TYPE,
	MC_TORQUE_CONTROL_TYPE,
	MC_THROTTLE_TYPE,
	MC_IDLE_VOLTAGE,
	MC_IDLE_CURRENT,
	MC_NUM_SETTINGS };
unsigned char mcSettings[MC_NUM_SETTINGS];
unsigned char mcMinimums[MC_NUM_SETTINGS] = { 8, 1, 5, 5, 0, 0, 0, 1, 0, 0 };
unsigned char mcMaximums[MC_NUM_SETTINGS] = { 150, 180, 100, 100, 4, 3, 3, 3, 12, 20 };

#ifdef MONITOR
	char* mcErrors[MC_NUM_ERRORS] = {
		"     Status: OK     ",
		"  Status: Sleeping  ",
		"     Desat fault     ",
		"Current sensor fault",
		"  Temp sensor fault  ",
		"    Undervoltage    ",
		"     Overvoltage     ",
		"   Low 12v supply   ",
		"   Throttle error   ",
		"   Thermal cutback   ",
		"  Thermal shutdown  " };

	char* mcUnits[MC_NUM_SETTINGS] = { "V", "V", "A", "A", "", "", "", "", "V", "A" };
	char* mcNames[MC_NUM_SETTINGS] = {
		" Min Batt Volts ",
		" Max Motor Volts ",
		"Max Motor Current",
		" Max Batt Current ",
		" Thrtl Ramp Rate ",
		" Speed Control ",
		" Torque Control ",
		" Throttle Type ",
		" Idle Voltage ",
		" Idle Current " };

	char* mcThrottleTypes[4] = { "", "     0-5V     ", "   0-5kohm   ", "     HEPA     " };
	char* mcControlTypes[4] = { "    Linear    ", "Semiquadratic", "  Quadratic  ", "   Off   " };
#endif


enum { IDLE, PRECHARGING, RUNNING, CHARGING, STOPPED, SETUP };
char state;

enum { CORE_IDLE_STATE, CORE_SETUP_STATE, CORE_SETUP_EDIT_FUEL_GAUGE, CORE_SETUP_EDIT_TEMP_GAUGE };
#ifdef MONITOR
	const char cs1[] PROGMEM = "Idle";
	const char cs2[] PROGMEM = "Precharging";
	const char cs3[] PROGMEM = "Running";
	const char cs4[] PROGMEM = "Charging";
	const char cs5[] PROGMEM = "Stopped";
	const char cs6[] PROGMEM = "Setup";
	PROGMEM const char* const coreStatuses[] = { cs1, cs2, cs3, cs4, cs5, cs6 };
#endif

short ticksInCurrentState = 0;

enum { NO_ERROR,
	CORRUPT_EEPROM_ERROR,
	OVERCURRENT_WARNING,
	OVERCURRENT_SHUTDOWN,
	BMS_LOW_WARNING,
	SHUTDOWN_BY_BMS_ERROR,
	BMS_HIGH_WARNING,
	BMS_ENDED_CHARGE_ERROR,
	BMS_OVERTEMP,
	BMS_UNDERTEMP,
	LOW_SOC_ERROR,
	OVERTEMP_ERROR,
	ISOLATION_ERROR,
	LOW_12V_ERROR,
	PRECHARGE_FAILED_ERROR,
	CONTACTOR_SW_FAULT,
	BMS_COMMS_ERROR,
	CORE_COMMS_ERROR,
	NUM_ERRORS };

#ifdef MONITOR
	const char e0[] PROGMEM = "No error";
	const char e1[] PROGMEM = "Corrupt settings";
	const char e2[] PROGMEM = "Overcurrent warning";
	const char e3[] PROGMEM = "Overcurrent shutdown";
	const char e4[] PROGMEM = "BMS - Low cell";
	const char e5[] PROGMEM = "Shutdown by BMS";
	const char e6[] PROGMEM = "BMS - High cell";
	const char e7[] PROGMEM = "Charge ended by BMS";
	const char e8[] PROGMEM = "BMS - Overtemp";
	const char e9[] PROGMEM = "BMS - Undertemp";
	const char e10[] PROGMEM = "Low battery charge";
	const char e11[] PROGMEM = "Over-temperature";
	const char e12[] PROGMEM = "Isolation fault";
	const char e13[] PROGMEM = "Low 12V battery";
	const char e14[] PROGMEM = "Precharge failed";
	const char e15[] PROGMEM = "Contactor fault";
	const char e16[] PROGMEM = "BMS - Comms error";
	const char e17[]	PROGMEM = "No comms to EVMS";
	PROGMEM const char* const errorStrings[] = { e0,e1,e2,e3,e4,e5,e6,e7,e8,e9,e10,e11,e12,e13,e14,e15,e16,e17 };
#endif

enum { // MPI functions
	MPI_WAKE_UP = 0,
	MPI_DUAL_CHARGE_RATE,
	MPI_HEADLIGHT_SENSE,
	MPI_CTR_AUX_SWITCH,
	MPI_NUM_FUNCTIONS };

#ifdef MONITOR
	const char mpi1[] PROGMEM = "Wake up";
	const char mpi2[] PROGMEM = "Alt charge";
	const char mpi3[] PROGMEM = "Hdlight in";
	const char mpi4[] PROGMEM = "Ctr aux sw";
	PROGMEM const char* const mpiStrings[] = { mpi1, mpi2, mpi3, mpi4 };
#endif

enum { // MPO functions
	MPO_GROUND,
	MPO_TEMP_GAUGE,
	MPO_LOW_SOC_SIGNAL,
	MPO_OVERTEMP_SIGNAL,
	MPO_UNDERTEMP_SIGNAL,
	MPO_ERROR_BUZZER,
	MPO_STATUS_LIGHT,
	MPO_NUM_FUNCTIONS };

#ifdef MONITOR
	const char mpo1[] PROGMEM = "Ground";
	const char mpo2[] PROGMEM = "Temp gauge";
	const char mpo3[] PROGMEM = "Low SoC";
	const char mpo4[] PROGMEM = "Overtemp";
	const char mpo5[] PROGMEM = "Undertemp";
	const char mpo6[] PROGMEM = "Error";
	const char mpo7[] PROGMEM = "Status";
	PROGMEM const char* const mpoStrings[] = { mpo1, mpo2, mpo3, mpo4, mpo5, mpo6, mpo7 };
#endif

enum { SOC_PERCENT, SOC_AMPHOURS };
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

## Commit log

2022-04-24 Set defaults to bike settings. Start framing in the motor page
2022-04-24 Switch to SoC and RPM on the motor page
2022-05-02 Only show fractional amps when current is below 10a
